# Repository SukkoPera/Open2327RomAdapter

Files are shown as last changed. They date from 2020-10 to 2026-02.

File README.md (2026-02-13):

# Open2327RomAdapter
Open2327RomAdapter is an Open Hardware adapter PCB that allows the use of a 27xxx EPROM in place of a 2364 and other PROMs. This is mainly useful for replacing the KERNAL and other ROMs in VIC-20 and Commodore 64 home computers and 1541 drives.

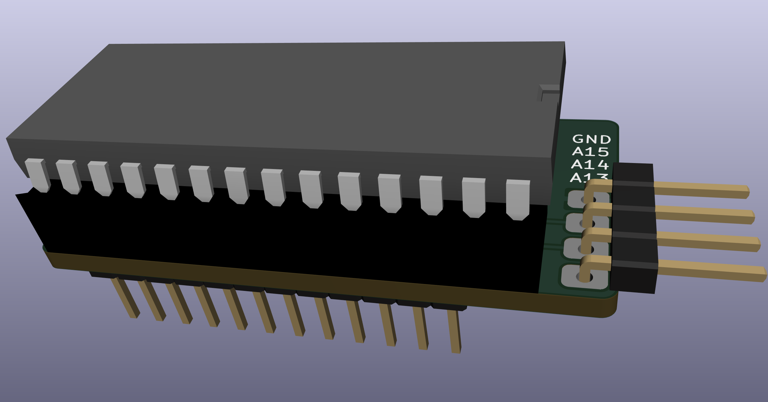
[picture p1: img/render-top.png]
Board


## Summary
The KERNAL ROM in a Commodore 64 is a 2364 model (8 KB), which comes in a 24-pin package. In some cases it is necessary to replace it, but 24-pin EPROMs are not easily available. Besides, in some cases you want to have multiple KERNAL ROMs that you can select with a switch (think about [JiffyDOS](http://www.go4retro.com/products/jiffydos/)).

Open2327RomAdapter comes as an adapter PCB that sits inbetween the original socket and the new chip and solves both those problems, by allowing the use of 28-pin EPROMs, which are cheaper and much more common. It also allows the use of EPROMs bigger than the original ROM, with solder pads where switches can be wired to allow the selection of a particular ROM.

## Assembly
1. Solder the R1-R3 0805 SMD resistors first (Note: do NOT install R4, see below). My suggested technique is as follows: put a small blob of solder on one of the pads, then grab a resistor with tweezers, reheat the solder and slide the resistor into it, keeping it flat on the board. Hold it in place with your tweezers and take the iron away. If you didn't place it straight, reheat and correct with the tweezers. Finally solder the other end. It's not that hard, you just need to practice a few times.
1. Put the pin headers into a solderless breadboard and lay the board on them, with the 0805 resistors facing down (i.e.: you should not see them). Make sure to use the two shortest hole series. Solder into place.
1. Remove the board from the solderless breadboard. Using flush cutters, cut the top two pins on the right (on the soldering side) so that they are as flush to the board as possible. Repeat with the bottom two pins. Take the socket and do a test fit, it should sit flush to the board.
1. Turn the board over and solder down the socket. Again, make sure it sits as flush as possible.
1. You are done! Try to fit the adapter in the socket on your board or solder it down, if you prefer. In both cases, you can trim the pins shorter if you need.

## Installation
Open2327RomAdapter has been designed with a Winbond W27C512 EEPROM in mind (and W27*E*512 should work just as well). This is a 64 KB chip (thus it can hold up to 8 ROM images, more than enough for most needs), which is widely available, cheap and electrically erasable, which avoids the need for a clunky UV-eraser. **This is the only part that was thoroughly tested**.

Three 0805 SMD resistors must be soldered to the bottom side of the board, according to the following table:

| (E)EPROM | Size  | # of images |  R1  |  R2  |  R3  | Switchable pads |
|---|---|---|---|---|---|---|
| 2764 | 8 KB  | 1 | 0R | 0R | 0R | - |
| 27128 | 16 KB | 2 | 10k  | 0R | 0R | A13 |
| 27256 | 32 KB | 4 | 10k  | 10k  | 0R | A13, A14 |
| 27512* | 64 KB | 8 | 10k  | 10k  | 10k  | A13, A14, A15 |

\* This is the only configuration that has been tested. **USE OTHER CONFIGURATIONS AT YOUR RISK!**

Note that `0R` means that you have to install a 0-ohm resistor. Alternatively you can bridge the pads with a solder blob, but don't leave the spot empty. Where the recommended value is `10k`, instead, you have some flexibility: probably any value between 5k and 100k will do.

When flashing the (E)EPROM, make sure that every file is exactly 8192 bytes long and just concatenate them. You don't need to use all of the available space, but keep in mind that the unused address lines are pulled high. This means that if you use a 27512 EPROM with a single image and no switches, for instance, the image must be flashed at $E000 (i.e.: as if it was the last of 8 concatenated images).

The adapter has been carefully sized to fit both inside a VIC-20 (tested on the KERNAL and BASIC ROMs on an Assy #250403 board) C64 (tested on the KERNAL of an Assy #250425 board) and a 1541 drive. It can usually be installed in the original ROM socket, with no need to desolder it.

To switch between ROMs, you will need one or more switches. Every switch must connect one of the A13-A15 pads to ground when enabled. A ground pad is available on the board, but any ground spot on the C64 board can be used as well, if easier to reach. Since having more than switch can be cumbersome, a rotary switch can be used as well.

### Replacing 2332 ROMs
2332 ROMs only hold 4 Kb of data. This means that you can switch among even more ROM images if you use a bigger EPROM. In order to do this, you will need to free the A12 address line, which requires a few extra steps:
1. Solder a 10k resistor at R4.
1. Cut the JP1 jumper open.
1. Solder another switch between the A12 pad on the bottom of the board and ground.

**IMPORTANT: ALWAYS TURN YOUR C64 OFF BEFORE MOVING THE ROM SELECTION SWITCH(ES).**

## License
The Open2327RomAdapter documentation, including the design itself, is copyright &copy; SukkoPera 2017-2020.

Open2327RomAdapter is Open Hardware licensed under the [CERN OHL v. 1.2](http://ohwr.org/cernohl).

You may redistribute and modify this documentation under the terms of the CERN OHL v.1.2. This documentation is distributed *as is* and WITHOUT ANY EXPRESS OR IMPLIED WARRANTIES whatsoever with respect to its functionality, operability or use, including, without limitation, any implied warranties OF MERCHANTABILITY, SATISFACTORY QUALITY, FITNESS FOR A PARTICULAR PURPOSE or infringement. We expressly disclaim any liability whatsoever for any direct, indirect, consequential, incidental or special damages, including, without limitation, lost revenues, lost profits, losses resulting from business interruption or loss of data, regardless of the form of action or legal theory under which the liability may be asserted, even if advised of the possibility or likelihood of such damages.

A copy of the full license is included in file [LICENSE.pdf](LICENSE.pdf), please refer to it for applicable conditions. In order to properly deal with its terms, please see file [LICENSE_HOWTO.pdf](LICENSE_HOWTO.pdf).

The contact points for information about manufactured Products (see section 4.2) are listed in file [PRODUCT.md](PRODUCT.md).

Any modifications made by Licensees (see section 3.4.b) shall be recorded in file [CHANGES.md](CHANGES.md).

The Documentation Location of the original project is https://github.com/SukkoPera/Open2327RomAdapter/.

## Support the Project
If you want to support the project, you can order the boards from PCBWay through this link:

PCB from PCBWay (https://www.pcbway.com/project/shareproject/Open2327RomAdapter_V3.html)

You get my gratitude and cheap, professionally-made and good quality PCBs, I get some credit that will help with this and [other projects](https://www.pcbway.com/project/member/shareproject/?bmbid=41100). You won't even have to worry about the various PCB options, it's all pre-configured for you!

Also, if you still have to register to that site, [you can use this link](https://www.pcbway.com/setinvite.aspx?inviteid=41100) to get some bonus initial credit (and yield me some more).

You can also buy me a coffee if you want:



## Get Support
If you need help or have questions, you can join [the official Telegram group](https://t.me/joinchat/HUHdWBC9J9JnYIrvTYfZmg).

## Thanks
The following links were useful during the development of this project:
- https://ist.uwaterloo.ca/~schepers/roms.html
- https://ist.uwaterloo.ca/~schepers/sockets.html
- http://smisioto.no-ip.org/elettronica/kicad/kicad.htm

The following people contributed work:
- Andre Miller helped with the testing.
- Tim Abraham suggested and tested the A12 hack.

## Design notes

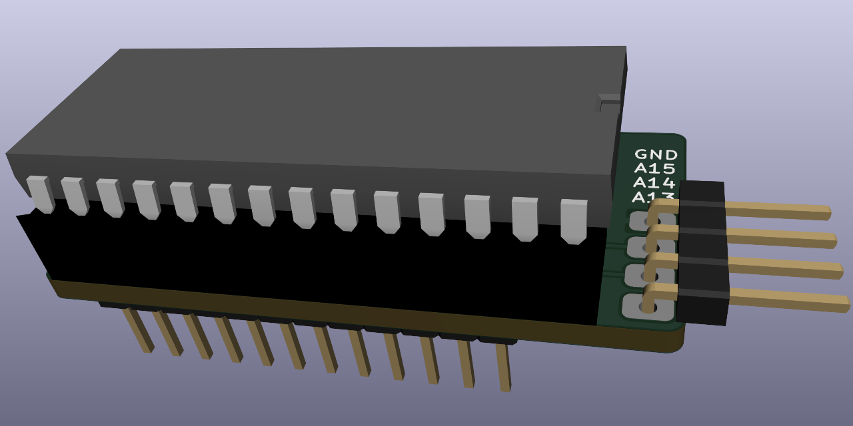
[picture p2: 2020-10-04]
img/social.png

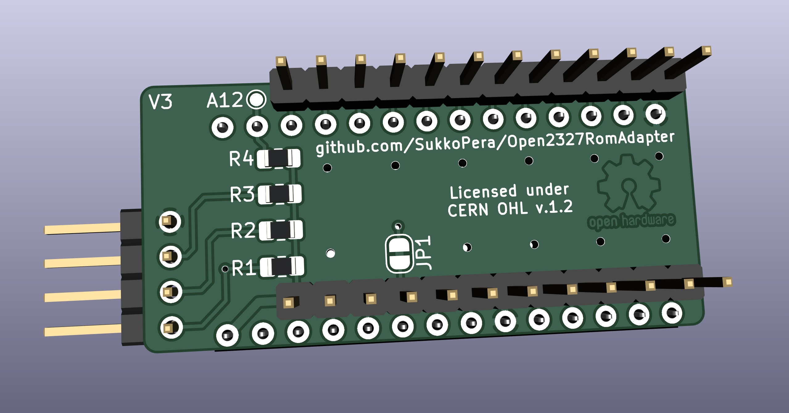
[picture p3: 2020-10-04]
img/render-bottom.png

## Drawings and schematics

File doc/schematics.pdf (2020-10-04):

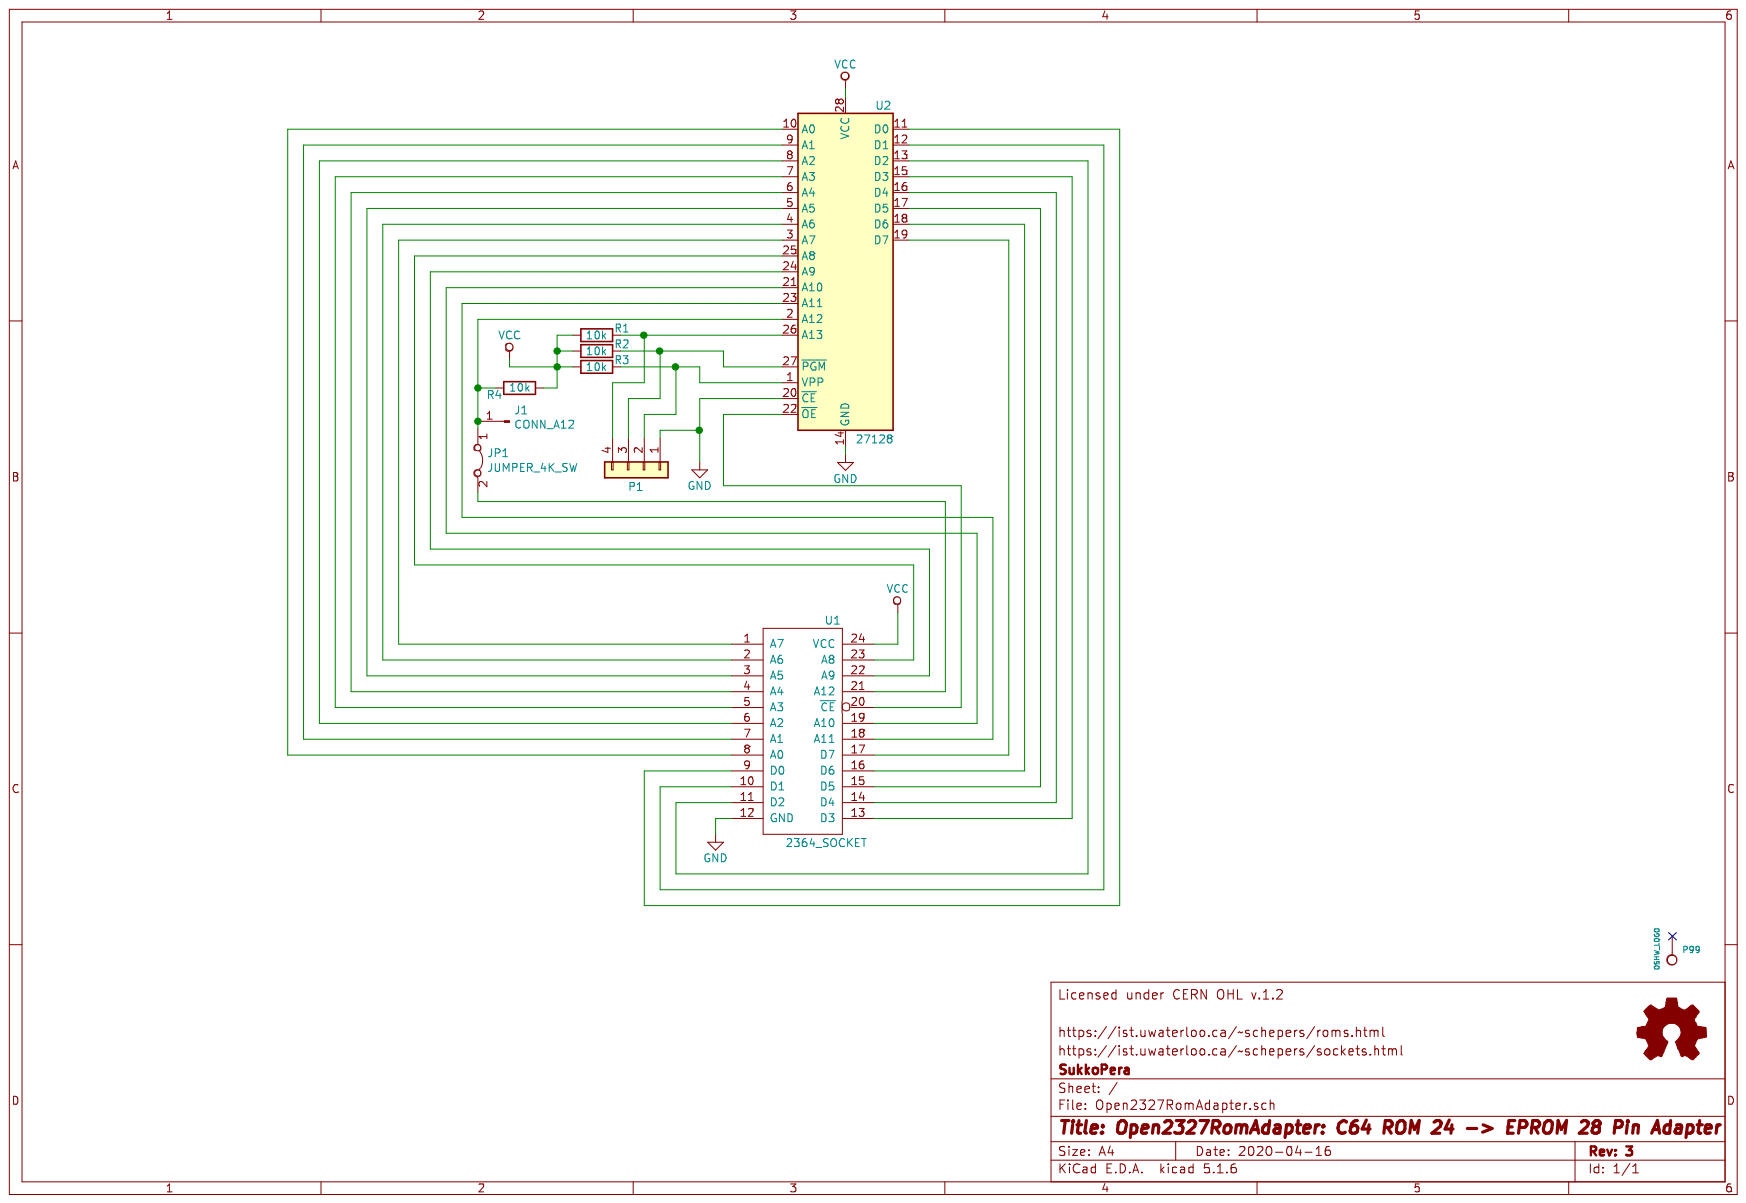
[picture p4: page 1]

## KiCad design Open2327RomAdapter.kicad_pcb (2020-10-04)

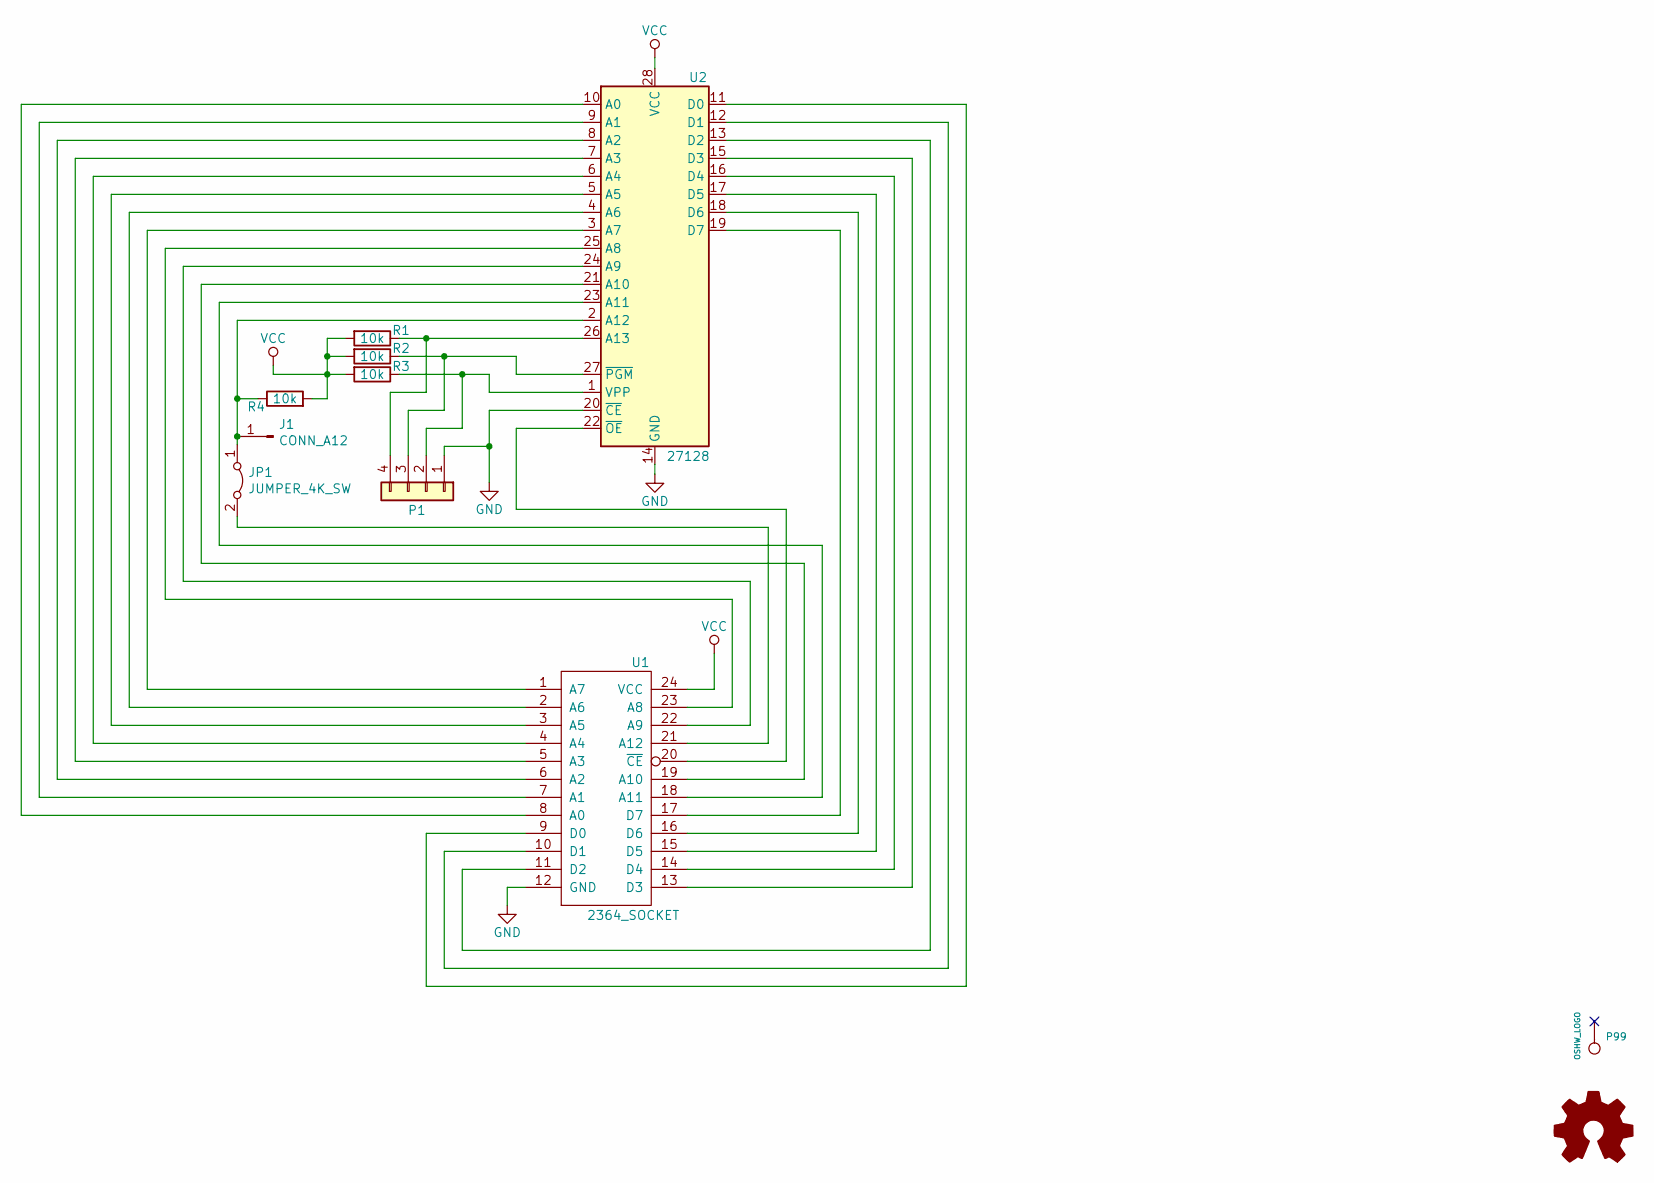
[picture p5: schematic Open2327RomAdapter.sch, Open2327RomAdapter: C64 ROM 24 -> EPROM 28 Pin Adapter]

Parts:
J1: CONN_A12; TestPoint_Pad_D1.0mm
JP1: JUMPER_4K_SW; SolderJumper-2_P1.3mm_Bridged_RoundedPad1.0x1.5mm
P1: Conn_01x04; Solderable_PinHeader_1x04
P99: OSHW_LOGO; OSHW-Logo2_7.3x6mm_Copper
R1, R2, R3, R4: 10k; R_0805_2012Metric_Pad1.15x1.40mm_HandSolder
U1: 2364_SOCKET; DIP-24_W15.24mm-Notch
U2: 27128; DIP-28_W15.24mm-Notch

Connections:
GND: P1.1, U1.12 (GND), U2.14 (GND), U2.20 (~CE)
unnamed: J1.1, JP1.1 (A), R4.1, U2.2 (A12)
unnamed: JP1.2 (B), U1.21 (A12)
unnamed: P1.2, R3.1, U2.1 (VPP)
unnamed: P1.3, R2.1, U2.27 (~PGM)
unnamed: P1.4, R1.1, U2.26 (A13)
unnamed: U1.1 (A7), U2.3 (A7)
unnamed: U1.2 (A6), U2.4 (A6)
unnamed: U1.3 (A5), U2.5 (A5)
unnamed: U1.4 (A4), U2.6 (A4)
unnamed: U1.5 (A3), U2.7 (A3)
unnamed: U1.6 (A2), U2.8 (A2)
unnamed: U1.7 (A1), U2.9 (A1)
unnamed: U1.8 (A0), U2.10 (A0)
unnamed: U1.9 (D0), U2.11 (D0)
unnamed: U1.10 (D1), U2.12 (D1)
unnamed: U1.11 (D2), U2.13 (D2)
unnamed: U1.13 (D3), U2.15 (D3)
unnamed: U1.14 (D4), U2.16 (D4)
unnamed: U1.15 (D5), U2.17 (D5)
unnamed: U1.16 (D6), U2.18 (D6)
unnamed: U1.17 (D7), U2.19 (D7)
unnamed: U1.18 (A11), U2.23 (A11)
unnamed: U1.19 (A10), U2.21 (A10)
unnamed: U1.20 (~CE), U2.22 (~OE)
unnamed: U1.22 (A9), U2.24 (A9)
unnamed: U1.23 (A8), U2.25 (A8)
VCC: R1.2, R2.2, R3.2, R4.2, U1.24 (VCC), U2.28 (VCC)

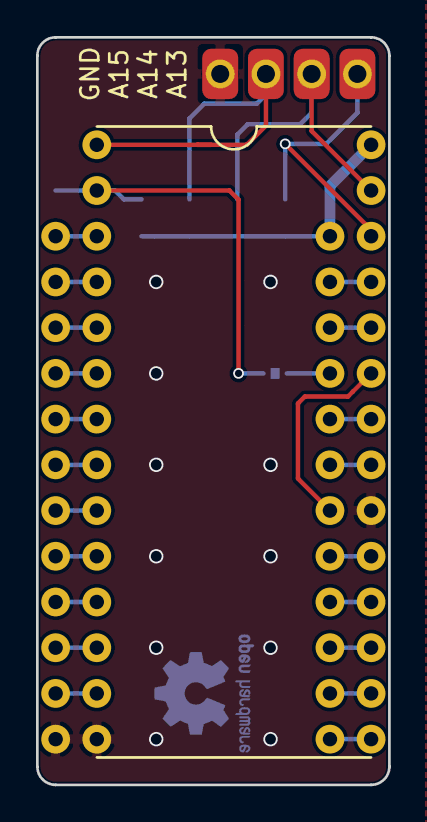
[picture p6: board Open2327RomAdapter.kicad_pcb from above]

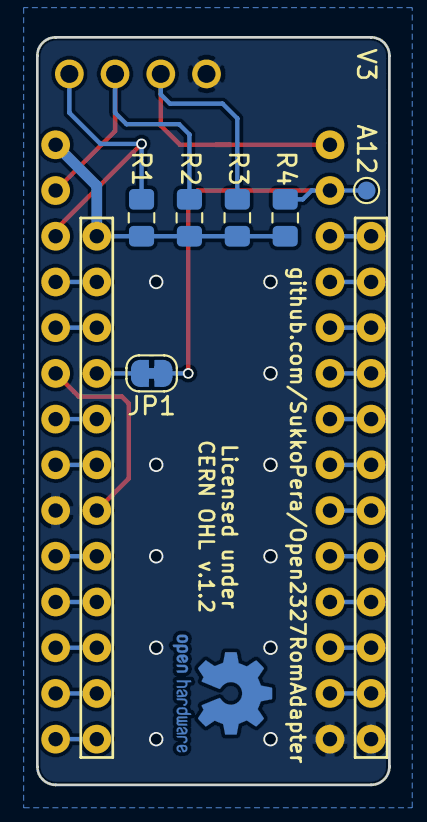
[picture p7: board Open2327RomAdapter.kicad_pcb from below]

Board: 2 copper layers, 19.6 x 41.5 mm, 10 parts (7 on the bottom side), 28 nets.

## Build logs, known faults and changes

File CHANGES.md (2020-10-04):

## CHANGES

Any modifications to the Open2327RomAdapter design and documentation made by any Licensee MUST be noted in this file, as per *section 3.4.b* of the [license](LICENSE.pdf).

### (Date) - (Author)
(Description)

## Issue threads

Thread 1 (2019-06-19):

table of size, amount of images and resistors is incorrect

patzik, 2019-06-19:
I think you got the table the wrong way around :-)

SukkoPera, 2019-06-19:
Uhm, no, it looks correct to me. Can you explain what you think is wrong and why?

patzik, 2019-06-19:
Never mind, I read it incorrectly, you are absolutely right....

Closed 2019-06-19.

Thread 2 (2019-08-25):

Make resistor table clearer

SukkoPera, 2019-08-25:
0 means 0 ohm, not to skip the resistor. Let's make it clearer.

Closed 2019-08-26.

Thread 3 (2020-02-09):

Tested : 27C64

andremiller, 2020-02-09:
Hi there,

I just wanted to give some feedback, as you mentioned on the main page that 27C64 should work, but has not been tested.

I've tested your adapter board, soldering bridges across all three resistor positions, and a 27C64 programmed with the standard 8K Kernal ROM (kernal.901227-03.bin) works perfectly as a replacement for the standard Kernal.

Further details:
- NMC27C64Q EPROM
- TL866II Programmer
- ROM: http://www.zimmers.net/anonftp/pub/cbm/firmware/computers/c64/kernal.901227-03.bin

Thanks for making this available!

SukkoPera, 2020-02-09:
Thanks andre, I will update the table ASAP!

Closed 2020-10-04.

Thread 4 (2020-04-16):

C64 Character Rom

timmit99, 2020-04-16:
For a second version, would it be possible to have a jumper pad that is normally closed (connected) for address line 12? for the 4K character ROM's you can put 2 on a 28C64 and by toggling A12 can switch between the two.

If you have a cuttable trace jumper and on address line 12 and then a pin header/solder pad for the line it can ALSO be toggled to allow for more switching

SukkoPera, 2020-04-16:
Like this?

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

timmit99, 2020-04-17:
exactly! yeah, that would keep it connected for 99% of the applications, but if you wanted to use a 4K ROM image for character sets you can just cut that jumper and then toggle the A12 line

SukkoPera, 2020-04-17:
Ok, I even managed to sneak in a pull-up resistor for A12.

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

Would you be willing to test this yourself, @timmit99? I mean get boards, etc.

timmit99, 2020-04-20:
@SukkoPera yeah, if you send me gerbers i'll throw in an OSH park order and test them with my CharSetRoms!

SukkoPera, 2020-04-21:
OK, send me an e-mail to mynick at gmail so that I have your address.

SukkoPera, 2020-04-21:
OK, send me an e-mail to mynick at gmail so that I have your address.

timmit99, 2020-04-21:
Could you just drop the gerber.zip here?

SukkoPera, 2020-04-22:
Nope, I don't want them to be public.

timmit99, 2020-04-22:
Email sent!

timmit99, 2020-04-23:
Can you confirm you got it?

SukkoPera, 2020-04-23:
I didn't! Maybe you didn't replace `mynick` with... my nick? :)

timmit99, 2020-04-23:
resent!

SukkoPera, 2020-04-23:
Sent :).

timmit99, 2020-04-24:
Ordered through JLC with a few other projects, Will report back later.
Might fork this and change the layout a bit so A12 can be exposed on the edge as well.

timmit99, 2020-05-05:
Works perfectly.
With an AT28C64 with two character ROM images on it. Cut the jumper pad (JP1) and put a 10K resistor on R4 with R1, R2, and R3 as 0 Ohm jumpers.

Connected a switch between the A12 pad and the ground pad and when switching it i can toggle between the two character sets.

SukkoPera, 2020-05-06:
Thanks for testing and glad it works. I'm leaving this open so that I remember to release the new adapter and update the docs.

timmit99, 2020-05-07:
If you need any information from me let me know! I can get some photos if you want.

Obiwantje, 2020-08-29:
Any chance I can get my hands on this new Gerber please? Going to test on C64 CHAR ROM

Closed 2020-10-04.

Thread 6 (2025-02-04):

Extending this for a hn61256 32K ROM

hexbus, 2025-02-04:
Have you ever thought about creating a version of this for a HN61256 (or larger) 32K Mask ROM?  You're just about there with this one, but many people want to use a 32K or 64K EPROM with the HN61256 as well.  Almost every pin is the same on the bottom except Vcc on the top right, which is moved up.

Many of the mask ROMs used this same strange pinout for their 16K and 32K mask ROMs, and many vintage users have been struggling with making adapters for years.  If you wanted to extend your adapter and trial it, I'd be more than happy to help.

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

SukkoPera, 2025-02-05:
Hi, what systems use these ROMs?

The project sounds rather simple anyway, I might think about it, but have you considered doing it yourself?

(Not intending to be mean, just a suggestion to pick up KiCad as this looks very good as a first project!)

hexbus, 2025-02-06:
Hi, @SukkoPera!

Thanks for your reply. The TI Compact Computer 40, TI-74, and TI-95 all use this mask ROM (http://www.datamath.org/ROM_IC.htm#Mask%20ROM) for an in-console ROM, while the CC-40 also uses them for cartridges.  Ironic is that the pinout is very similar to the Tandy 61256’s, but not exact.

I came across your site because of the excellent collection of adapters you’ve made available to the community!

I raised the issue for the 61256 for several reasons. Firstly, I saw you were centralizing a collection of these adapters in a single repository, and would love to keep it simple for people to find these. Secondly, since you’ve completed numerous other adapters, you’re more familiar with how the control pins usually function (OE, CE, etc.).

I also have some background knowledge about the address, data, voltage, and ground pins, but I’m completely clueless about adapting the other ones. I’m more than willing to assist in debugging the board and ensuring it works with the 74 and CC-40 if you’re willing to help take a stab at helping me figure it out.

I’m also fine with modifying existing KiCAD layouts to suit my needs. (Check out my own repository for a power supply board that I modified.) Some projects prefer working on their own designs more than others, so it’s best to discuss this with the repository owner like we’re doing now. :)

If you have an existing board that you suggest as a starting point for this project, I’m willing to begin working on it to adjust the pins. I can also learn how to branch it and try to propose a merge back to your repo (which I haven’t done before.). However, I’ll need some assistance, and I’d greatly appreciate it if we could use your repository as the final destination for the project so that we can keep these designs in one centralized location. Please let me know your thoughts on this.  I’m all for learning!  Thank you again for the hard work!

SukkoPera, 2025-02-06:
I think this deserves to be a separate project, since making a single adapter would make it a nightmare to configure and since anyway this is one of my oldest KiCad projects (it could actually be the first one I ever did, it was started in KiCad 4 for sure!) and now I would do things a bit differently...

... which in fact I did, here's what I came up with:

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

I have a few doubts about the CE/CS pins, since I found (this datasheet)[https://www.datasheets360.com/part/detail/hn61256p/7282103330191539697/] and it points out that the active level of those pins is configurable at the mask level, so I'd need to know whether the particolar ROMs you want to replace are active-low or active high. Any idea?

SukkoPera, 2025-02-11:
@hexbus ? :)

hexbus, 2025-02-11:
Hey there - sorry, I've been busy with real life medical issues; my apologies!

Several years ago, my friend I rescued the long lost CC-40 schematics from a TI Engineer and scanned them and placed them in the public domain.  This has the module port and all its signals included (defaults).  I'm asking the developer of https://github.com/go4retro/HEXTIr if they know what the default levels are offhand and where they might need to be hooked up to, since I really don't know.

[1983_CC-40-final_schematics_and_block_diagram.pdf](https://github.com/user-attachments/files/18755556/1983_CC-40-final_schematics_and_block_diagram.pdf)

I do have all of TI's schematics for cartridges for ROM/RAM and EPROM pinouts.  The pinout going to the CC-40 might have changed, but the name of the pins the chips connected to should not have:

ROM modules (61256):

One 61256: [CC-40_ALC_Application_ROM_Module_Jan_1983.pdf](https://github.com/user-attachments/files/18756303/CC-40_ALC_Application_ROM_Module_Jan_1983.pdf)

Two 61256: [CC-40_2-16KX8_32Kx8_ROM_Module_Feb_1983.pdf](https://github.com/user-attachments/files/18756301/CC-40_2-16KX8_32Kx8_ROM_Module_Feb_1983.pdf)

Battery Backed up RAM:

One 6116: [CC-40_2KX8_8KX8_RAM_Battery_Module.pdf](https://github.com/user-attachments/files/18756302/CC-40_2KX8_8KX8_RAM_Battery_Module.pdf)

RAM Cart:

Two 8K x 8: [CC-40-two-8Kx8_RAM-module-1983.pdf](https://github.com/user-attachments/files/18756304/CC-40-two-8Kx8_RAM-module-1983.pdf)

EPROM Example:

Two 2764s:  [CC-40_16K-eprom-cartridge_1983.pdf](https://github.com/user-attachments/files/18756305/CC-40_16K-eprom-cartridge_1983.pdf)

I'm continuing to dig and might have some additional schematics.

hexbus, 2025-02-11:
Adding these - I forgot that I had these on an old 486, so I might as well put them out in the public; an old friend sent them to me.  These should help immensely and be much easier to read:

(Combo 27512 and 62256 RAM):
[cc40m2ro.pdf](https://github.com/user-attachments/files/18756666/cc40m2ro.pdf)

(6264 battery backed up RAM):
[cc40m8k.pdf](https://github.com/user-attachments/files/18756668/cc40m8k.pdf)

(6264 x 2 battery backed up RAM):
[cc40m16k.pdf](https://github.com/user-attachments/files/18756670/cc40m16k.pdf)

(27512 EPROM - probably what we want!):
[cc40mech.pdf](https://github.com/user-attachments/files/18756669/cc40mech.pdf)

61256 regular cartridge pinout (what we've been trying to clone or figure out):
[cc40mmp.pdf](https://github.com/user-attachments/files/18756671/cc40mmp.pdf)

(2764 x 2 EPROM cartridge):
[cc40rom2.pdf](https://github.com/user-attachments/files/18756667/cc40rom2.pdf)

SukkoPera, 2025-02-12:
Thanks a lot for the documents. All evidence seems to point to CS being active-high and /CE being active low. I will have to think about it.

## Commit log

2017-09-27 Add pull-up resistors
    [Open2327RomAdapter.sch]
2017-09-27 Move pull-up resistors to bottom of board
    [Open2327RomAdapter.kicad_pcb]
2017-09-27 Update board This should be the board that went to prototype production. It has been tested and is working great!
    [Open2327RomAdapter.kicad_pcb, Open2327RomAdapter.sch]
2017-10-10 Minor fixes
    [Open2327RomAdapter.kicad_pcb, Open2327RomAdapter.sch]
2017-11-08 Add assembly instructions
2017-12-30 Fix URL, better ground plane, round corners
    [Open2327RomAdapter.kicad_pcb]
2018-01-05 Final touches for V2
    [Open2327RomAdapter.kicad_pcb, Open2327RomAdapter.sch]
2019-05-05 Move solderable pads to 0.1" pitch and drill a hole through them Also port to Kicad 5 and use builtin components/footprints
    [Open2327RomAdapter.kicad_pcb, Open2327RomAdapter.sch]
2019-05-05 Update renders and schematic PDF
2019-05-05 Add P99 description
    [Open2327RomAdapter.sch]
2019-05-05 Make corners more rounded
    [Open2327RomAdapter.kicad_pcb]
2019-05-05 Fix ERC
    [Open2327RomAdapter.sch]
2020-04-23 Add jumper, pull-up and pad so that A12 can optionally be driven externally
    [Open2327RomAdapter.kicad_pcb, Open2327RomAdapter.sch]
2020-10-04 Update schematics
2020-10-04 Update board link

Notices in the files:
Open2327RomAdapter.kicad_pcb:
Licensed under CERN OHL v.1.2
